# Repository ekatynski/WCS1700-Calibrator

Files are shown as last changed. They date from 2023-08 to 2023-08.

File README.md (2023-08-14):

View this project on [CADLAB.io](https://cadlab.io/project/27238). 

# WCS1700-Calibrator
A board designed to aid in calibrating six [Winson WCS1700 hall effect sensors](https://www.winson.com.tw/uploads/images/WCS1700.pdf) at the same time as well as the software needed to drive it.

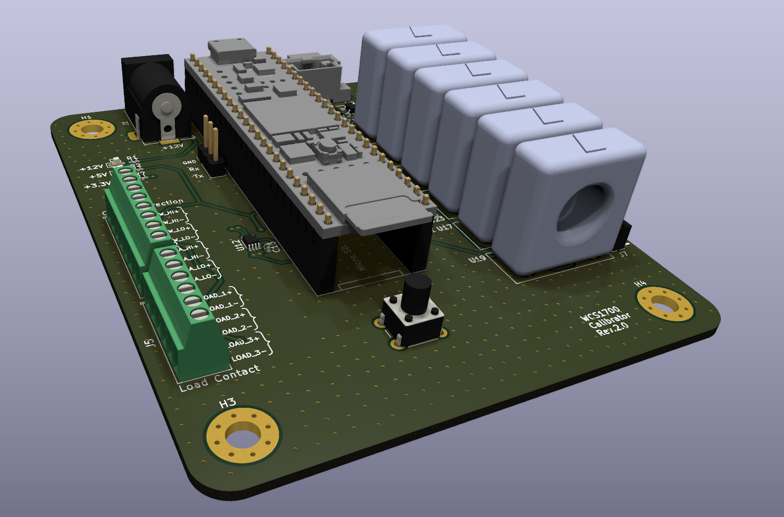
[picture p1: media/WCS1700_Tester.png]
Rendering of the completed PCB


## Requirements
1. +12V power supply rated for at least 1A with barrel jack connection (+8V will work in a pinch)
2. An adjustable current source capable of up to 60A output with a conductor small enough to fit the aperture of a WCS1700
3. A micro-USB cable with data capability
4. A Teensy 4.1 microcontroller and [completion of the necessary first use steps](https://www.pjrc.com/teensy/loader.html)
5. For best results, VSCode with the Platformio plugin installed

## Hardware
Schematic and BOM can both be found in the `/hardware/` section of this repository. Expanded description of hardware functionality coming soon.

## Software
All software can be found in the `/software/` section of this repository. Expanded description of software functionality coming soon. In addition, software updates to expand contactor control functionality and independent current volume is on the way, but the software necessary to simply monitor and report the WCS1700 hall effect sensor outputs is ready and implemented.

## Procedure
1. Slot one WCS hall effect sensor into each of the six ports on the right. This will feed them a +5V reference and allow their output voltages to be tracked via a nearby ADC
2. Inspect your Teensy 4.1. If the trace separating VIN and VUSB is cut, you should solder JP3 on the PCB. If not, you should ensure that either the aforementioned Teensy trace is intact or that the pads spanned by said trace are soldered together. **Do not do both or you risk damaging your Teensy or the board**
3. Ensure that JP1 and JP2 are not soldered simultaneously. It is okay to solder one or the other (or neither) but **do not do both or you risk damaging your board**
4. Seat your Teensy 4.1 in the pin sockets and connect it to your computer via USB
5. Route your current source conductor through the hall effect sensor apertures and attach a load
6. Apply power to the PCB
7. Monitor the serial output from the Teensy 4.1
8. Adjust your current source as desired

## Assembly Guide
An assembly guide for this board can be found in this repository at `/hardware/bom/`

## To-Do
The hardware of this project has advanced to support contactor control via relay connections. Four of these contactors form a would-be H-bridge to control load current flow direction while the remaining three allow current flow across individual load resistors to increase or decrease current volume. The hardware has also advanced to support independent current monitoring via a Tamura L01Z series hall effect sensor. The software to drive these features is not yet in place. The following is a list of development items not yet complete:

- [x] Rearrange FET position and routing to make it a superior low-side switch
- [ ] Add harness documentation
- [ ] Write code to support autocalibration of ADC `U4`
- [ ] Write code to support monitoring of Tamura L01Z Hall Effect sensor via ADC 'U5'
- [ ] Write logic to support contactor control during current monitoring after button push
- [ ] Write code to support logging recorded calibration values to an SD card
- [ ] Update instructions to allow for use of additional Tamura hall effect sensor as well as contactor control

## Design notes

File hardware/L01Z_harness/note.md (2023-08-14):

# Note:

This is retained more as a documentation example than a useful aspect. This harness usually leads to a small standalone board for better interfacing with the L01Z hall effect sensor but I haven't uploaded that, so it's not terribly useful here.

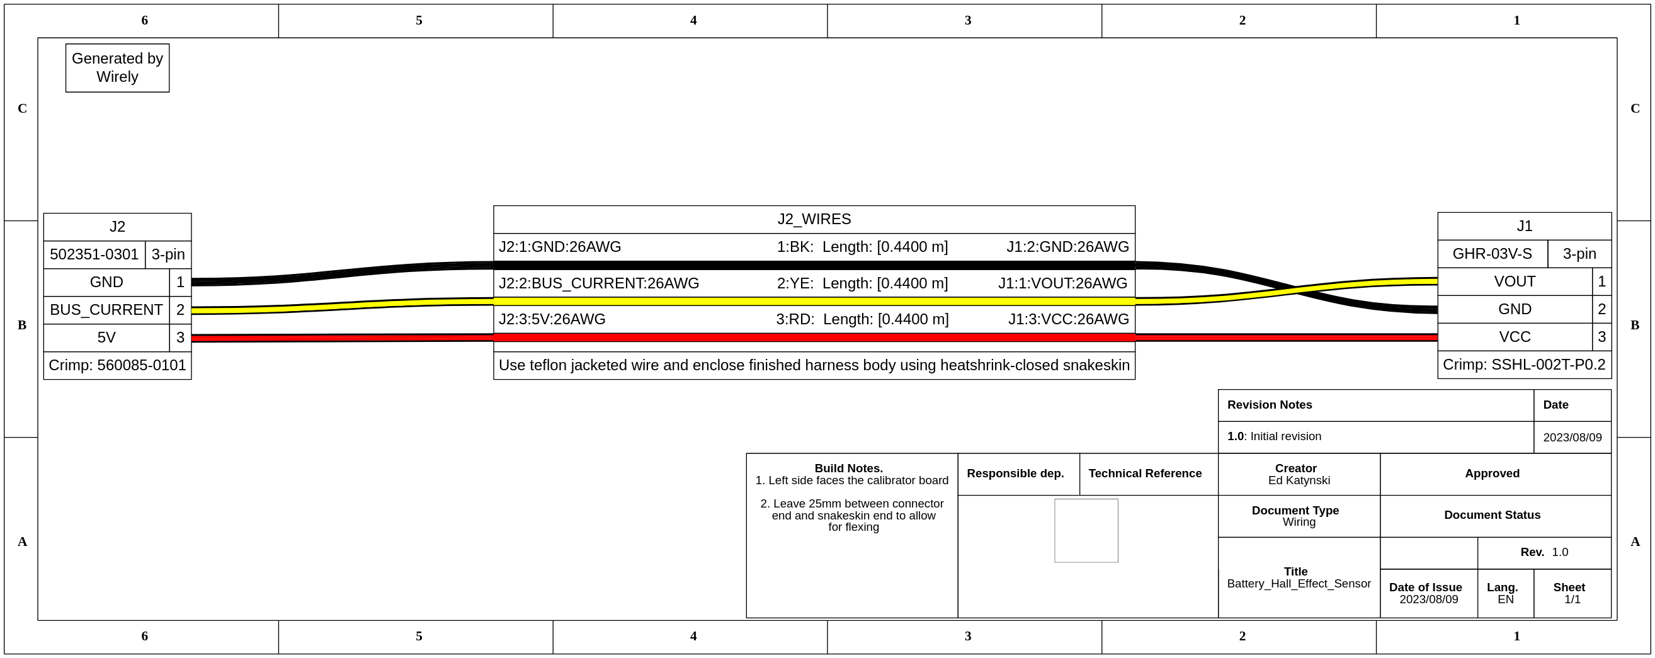
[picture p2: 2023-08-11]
hardware/L01Z_harness/Battery_Hall_Effect_Sensor.png

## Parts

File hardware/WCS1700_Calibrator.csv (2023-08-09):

Source: | /home/ed/Documents/KiCad/Work Projects/WCS1700-Calibrator/WCS1700_Calibrator.kicad_sch
Date: | Tue 08 Aug 2023 10:41:28 PM PDT
Tool: | Eeschema 7.0.6
Generator: | /app/share/kicad/plugins/bom_csv_grouped_by_value.py
Component Count: | 119
Collated Components:
Item | Qty | Reference(s) | Value | LibPart | Footprint | Datasheet | DNP | Application Note
1 | 18 | C1, C2, C10, C11, C12, C13, C15, C16, C18, C19, C21, C22, C24, C25, C27, C28, C30, C31 | 0.1uF 25V | Device:C | Capacitor_SMD:C_0402_1005Metric_Pad0.74x0.62mm_HandSolder | ~
2 | 5 | C3, C4, C5, C8, C9 | 1uF 25V | Device:C | Capacitor_SMD:C_0402_1005Metric_Pad0.74x0.62mm_HandSolder | ~
3 | 1 | C6 | 0.01uF 10V | Device:C_Small | Capacitor_SMD:C_0402_1005Metric_Pad0.74x0.62mm_HandSolder | ~
4 | 1 | C7 | 10uF 10V | Device:C | Capacitor_SMD:C_0402_1005Metric_Pad0.74x0.62mm_HandSolder | ~
5 | 6 | C14, C17, C20, C23, C26, C29 | 0.1uF 25V | Device:C_Small | Capacitor_SMD:C_0402_1005Metric_Pad0.74x0.62mm_HandSolder | ~
6 | 3 | D1, D3, D4 | 150060VS75000 | Device:LED | LED_SMD:LED_0603_1608Metric_Pad1.05x0.95mm_HandSolder | https://www.we-online.com/components/products/datasheet/150060VS75000.pdf
7 | 1 | D2 | B0520LW-7-F | Device:D_Schottky | Diode_SMD:D_SOD-123 | https://www.diodes.com/assets/Datasheets/B0520LW.pdf
8 | 4 | H1, H2, H3, H4 | MountingHole | Mechanical:MountingHole | MountingHole:MountingHole_4mm_Pad_Via | ~
9 | 1 | J1 | PJ-002B | Connector:Barrel_Jack_Switch | Connector_BarrelJack:BarrelJack_Horizontal | https://www.cuidevices.com/product/resource/pj-002b.pdf
10 | 1 | J2 | 560020-0330 | Connector_Generic_MountingPin:Conn_01x03_MountingPin | connector:CONN_560020-0330_MOL | https://tools.molex.com/pdm_docs/sd/5600200330_sd.pdf
11 | 1 | J3 | 282834-8 | Connector:Screw_Terminal_01x08 | TerminalBlock_TE-Connectivity:TerminalBlock_TE_282834-8_1x08_P2.54mm_Horizontal | https://www.te.com/usa-en/product-282834-8.datasheet.pdf
12 | 1 | J4 | Conn_01x03_Pin | Connector:Conn_01x03_Pin | Connector_PinHeader_2.54mm:PinHeader_1x03_P2.54mm_Vertical | ~
13 | 1 | J5 | 282834-6 | Connector:Screw_Terminal_01x06 | TerminalBlock_TE-Connectivity:TerminalBlock_TE_282834-6_1x06_P2.54mm_Horizontal | https://www.mouser.com/datasheet/2/418/7/ENG_CD_282834_C1-2036206.pdf
14 | 6 | J6, J7, J8, J9, J10, J11 | Conn_01x03_Socket | Connector:Conn_01x03_Socket | Connector_PinSocket_1.27mm:PinSocket_1x03_P1.27mm_Vertical | ~
15 | 3 | JP1, JP2, JP3 | Jumper_2_Open | Jumper:Jumper_2_Open | Jumper:SolderJumper-2_P1.3mm_Open_TrianglePad1.0x1.5mm | ~
16 | 5 | Q1, Q2, Q3, Q4, Q5 | AO3422 | Transistor_FET:AO3400A | Package_TO_SOT_SMD:SOT-23 | http://www.aosmd.com/pdfs/datasheet/AO3400A.pdf
17 | 13 | R1, R2, R7, R8, R9, R14, R15, R16, R17, R18, R19, R20, R21 | 4.7K | Device:R_US | Resistor_SMD:R_0402_1005Metric_Pad0.72x0.64mm_HandSolder | ~
18 | 4 | R3, R4, R5, R6 | 2.2K 0.1% | Device:R_US | Resistor_SMD:R_0402_1005Metric_Pad0.72x0.64mm_HandSolder | ~
19 | 7 | R10, R11, R12, R13, R22, R23, R24 | 500R | Device:R_US | Resistor_SMD:R_0402_1005Metric_Pad0.72x0.64mm_HandSolder | ~
20 | 1 | R25 | 10K | Device:R_US | Resistor_SMD:R_0402_1005Metric_Pad0.72x0.64mm_HandSolder | ~ | DNP
21 | 1 | SW1 | ‎1825910-6‎ | Switch:SW_Push | Button_Switch_THT:SW_PUSH_6mm_H8mm | https://media.digikey.com/pdf/Data%20Sheets/Panasonic%20Electronic%20Components/ESE-20C,D.pdf
22 | 1 | TH1 | 0ZCJ0050AF2E | Device:Thermistor_PTC_US | Fuse:Fuse_1206_3216Metric_Pad1.42x1.75mm_HandSolder | https://www.belfuse.com/resources/datasheets/circuitprotection/ds-cp-0zcj-series.pdf
23 | 6 | TP1, TP2, TP3, TP4, TP5, TP6 | TestPoint | Connector:TestPoint | TestPoint:TestPoint_Pad_D1.0mm | ~
24 | 2 | U1, U2 | MAX6107 | Reference_Voltage:MAX6107 | Package_TO_SOT_SMD:SOT-23 | http://datasheets.maximintegrated.com/en/ds/MAX6100-MAX6107.pdf
25 | 1 | U3 | LT1962EMS8-5#TRPBF | Regulator_Linear:LT1962-5 | Package_SO:MSOP-8_3x3mm_P0.65mm | https://www.analog.com/media/en/technical-documentation/data-sheets/1962fb.pdf
26 | 2 | U4, U5 | MCP3208 | :MCP3208_1 | Package_SO:SOIC-16_3.9x9.9mm_P1.27mm | http://ww1.microchip.com/downloads/en/DeviceDoc/21298c.pdf
27 | 1 | U6 | TXB0106PW | level_shift:TXB0106PW | Package_SO:TSSOP-16_4.4x5mm_P0.65mm | https://www.ti.com/lit/ds/symlink/txb0106.pdf
28 | 7 | U7, U8, U9, U10, U14, U15, U16 | TLP241A(TP1,F | Relay_SolidState:TLP222A | OptoDevice:OnSemi_CASE100CY | https://toshiba.semicon-storage.com/info/TLP241A_datasheet_en_20200217.pdf?did=14237&prodName=TLP241A
29 | 1 | U11 | SN74AUC2G08DCUR | 74xGxx:74AUC2G08 | Package_SO:VSSOP-8_2.3x2mm_P0.5mm | https://www.ti.com/lit/ds/symlink/sn74auc2g08.pdf
30 | 1 | U12 | 74LVC2G240DC,125 | 74xGxx:74LVC2G240 | Package_SO:VSSOP-8_2.3x2mm_P0.5mm | http://www.ti.com/lit/sg/scyt129e/scyt129e.pdf
31 | 1 | U13 | Teensy4.1 | teensy:Teensy4.1 | teensy:Teensy41
32 | 6 | U17, U19, U21, U23, U25, U27 | WCS1700 | Sensor_Hall_Effect:WCS1700 | Sensor_Hall_Effect:WCS1700 | http://www.winson.com.tw/uploads/images/WCS1700.pdf |  | http://www.winson.com.tw/uploads/images/WCS%20Application%20note.pdf
33 | 6 | U18, U20, U22, U24, U26, U28 | ADR02AUJZ | v_ref:ADR02AUJZ | Package_TO_SOT_SMD:SOT-23-5_HandSoldering | https://www.analog.com/media/en/technical-documentation/data-sheets/ADR01_02_03_06.pdf

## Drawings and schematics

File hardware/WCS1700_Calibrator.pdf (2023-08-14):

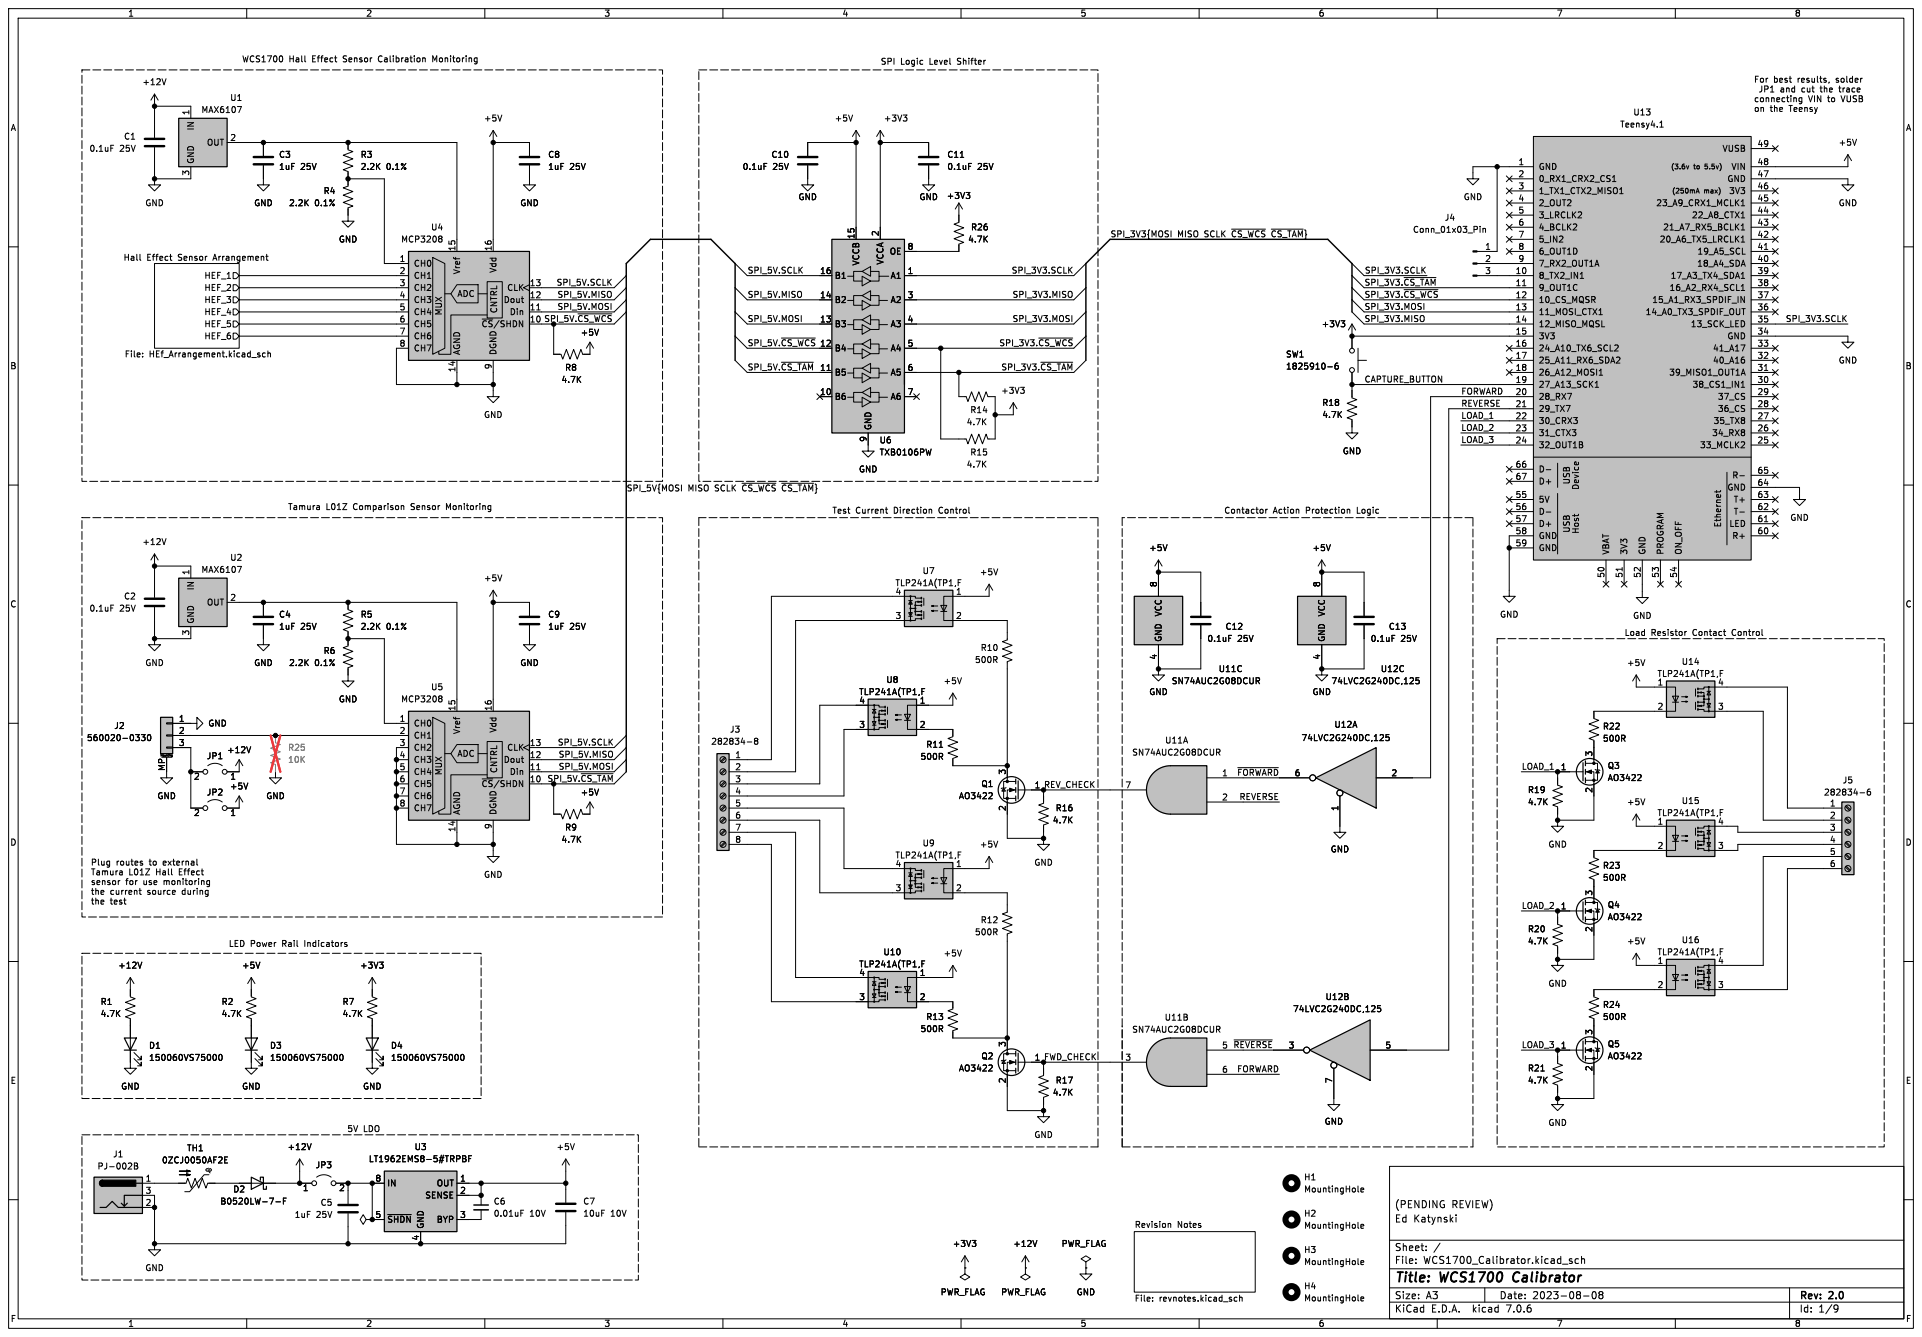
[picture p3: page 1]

Load Resistor Contact Control U11C

the current source during
the test

LED Power Rail Indicators

5V LDO
LT1962EMS8-5#TRPBF OUT 1 SENSE 2 BYP 3 GND

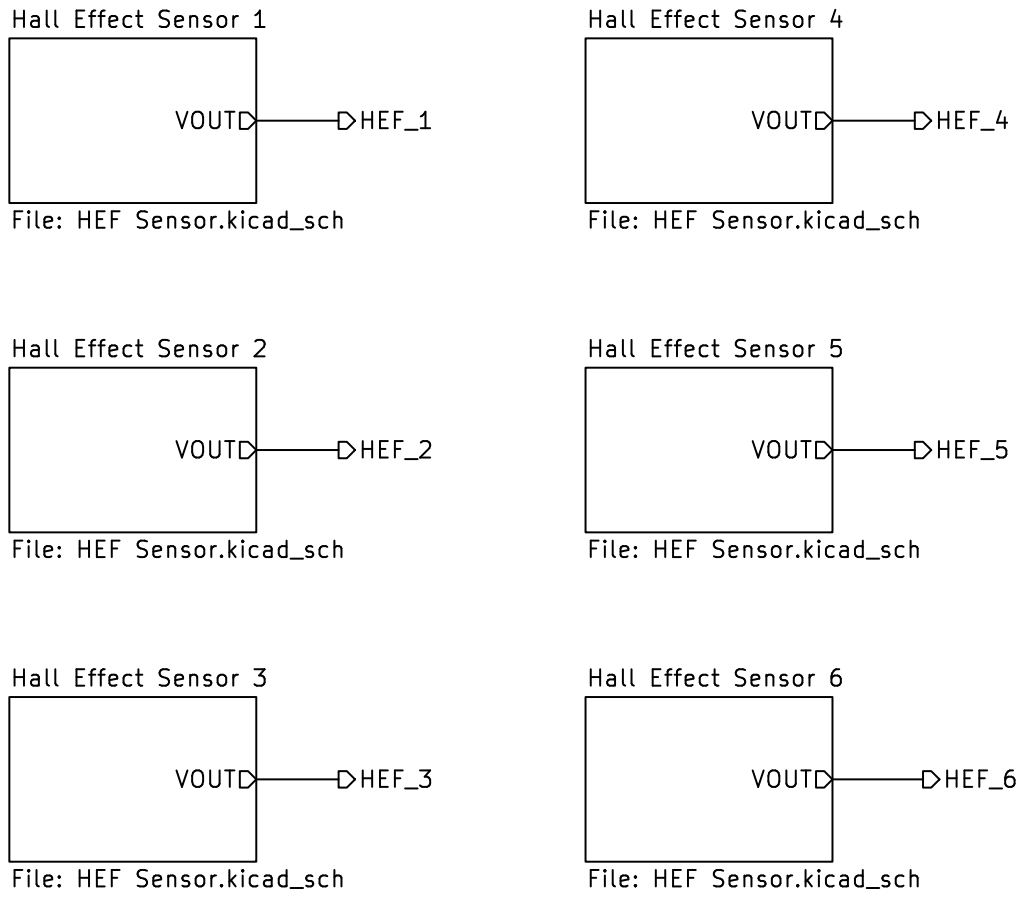
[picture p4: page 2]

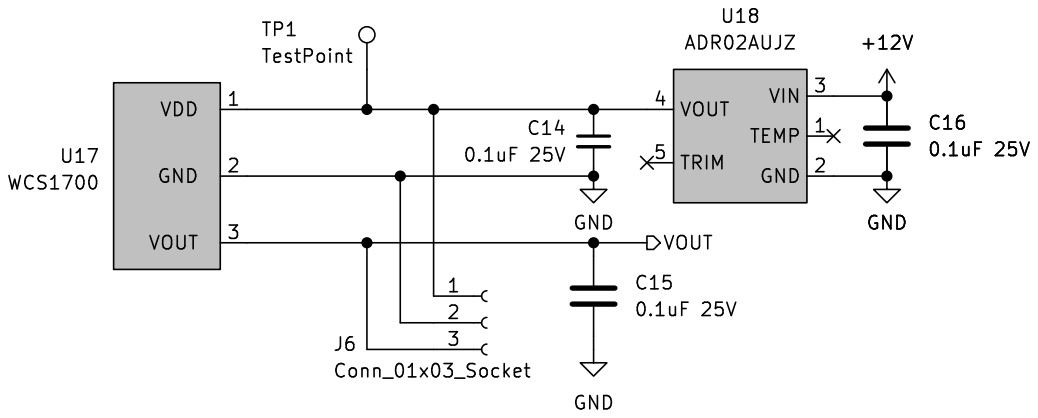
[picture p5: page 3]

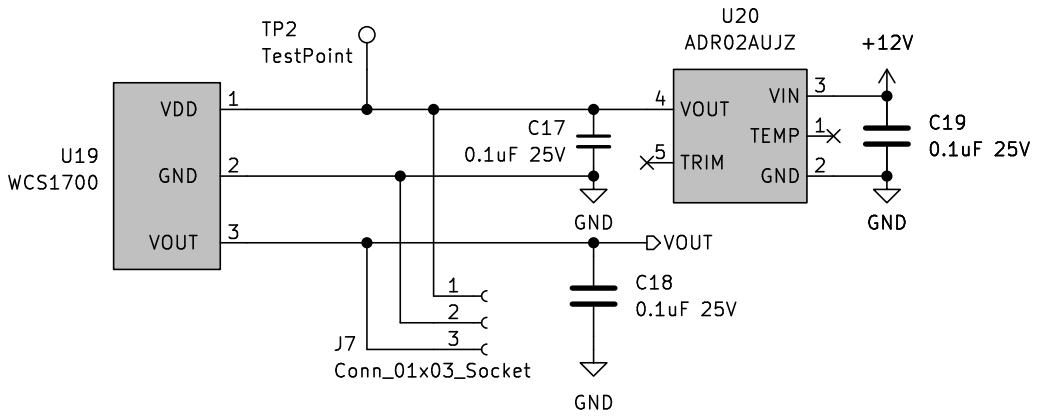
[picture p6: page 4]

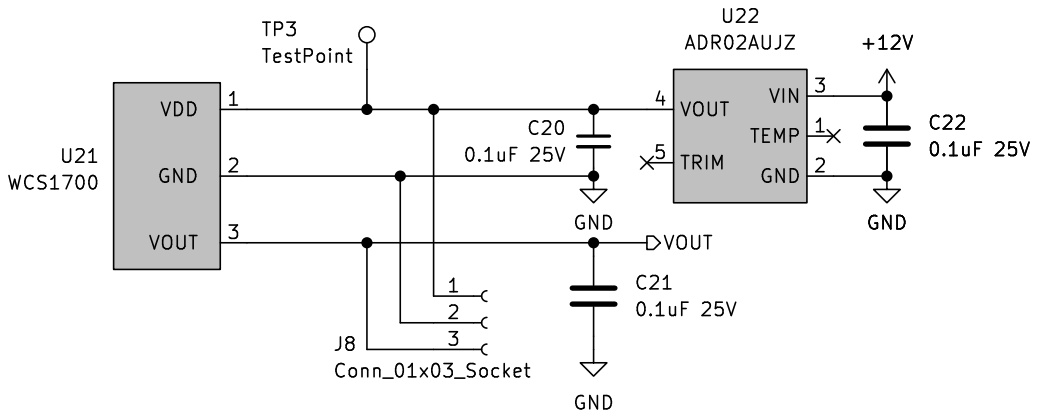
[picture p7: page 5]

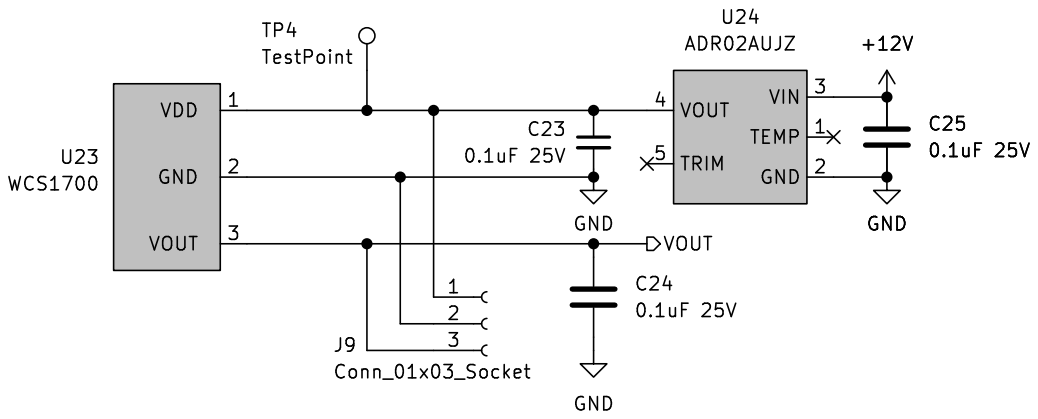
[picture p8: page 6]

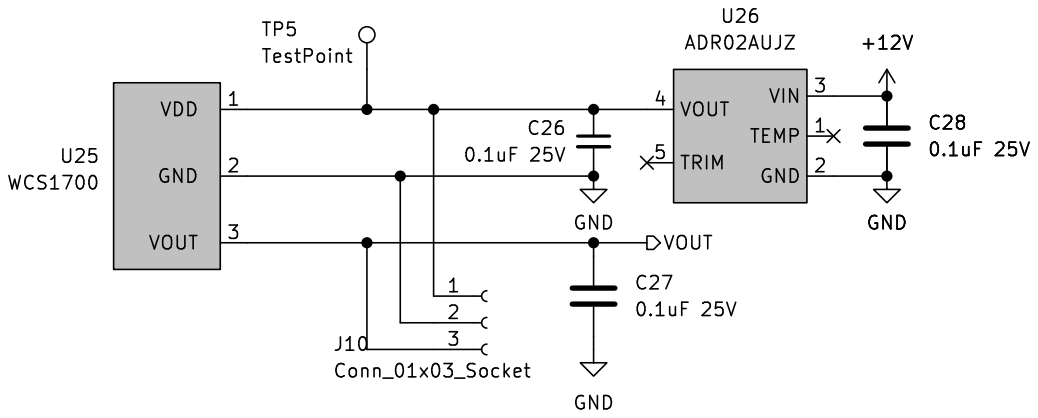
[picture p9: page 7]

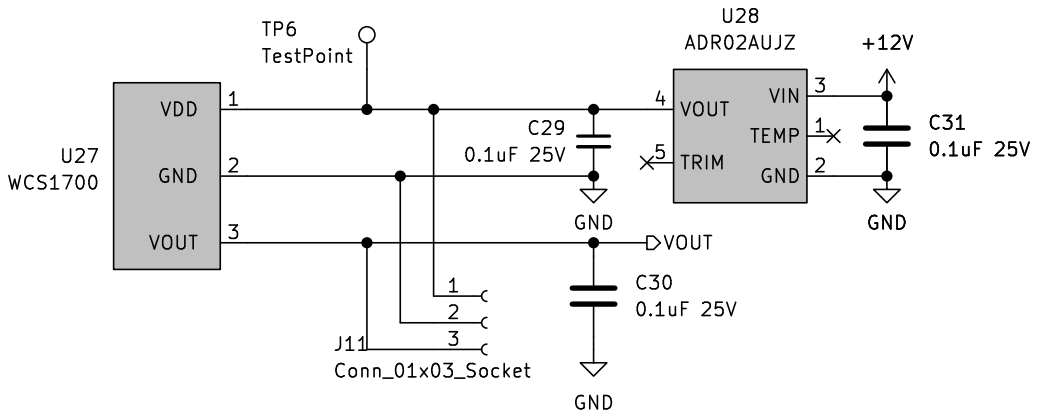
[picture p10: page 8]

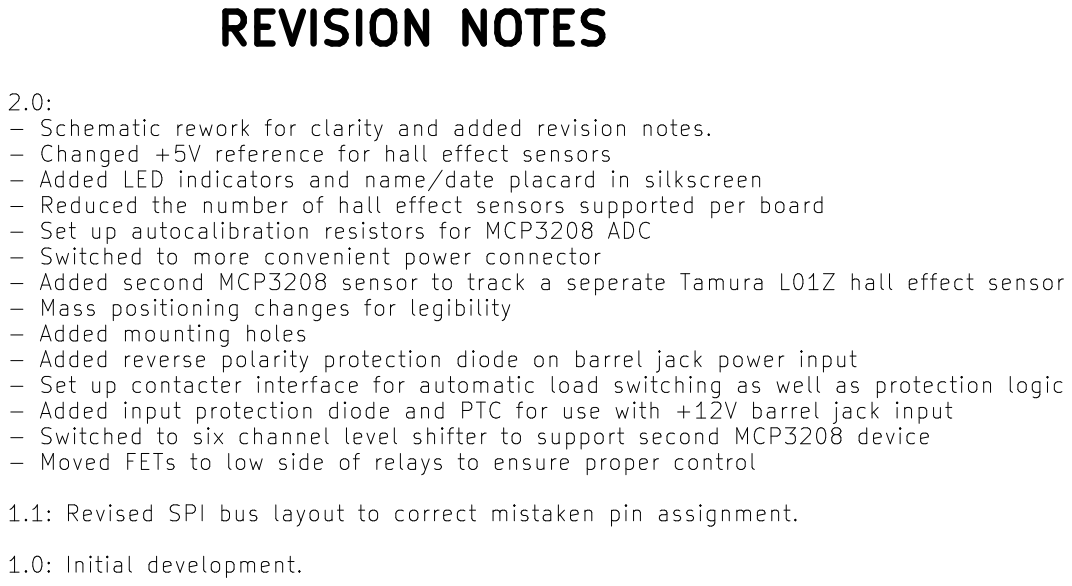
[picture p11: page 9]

- Moved FETs to low side of relays to ensure proper control

1.1: Revised SPI bus layout to correct mistaken pin assignment.

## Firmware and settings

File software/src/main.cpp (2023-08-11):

#include <Arduino.h>
#include <SPI.h>
#include <vector>
#include "Mcp320x.h"

const int WCS_CS = 10;        // WCS1700 ADC CS pin
const int TAMURA_CS = 11;     // Tamura hall effect sensor CS pin
const int ADC_VREF = 4500;    // 4.5V Vref
const int ADC_CLK = 500000;   // SPI clock 500kHz
const int SPLS = 10;          // 10 samples

float gain = 1.00;            // ADC gain, set by hand for now
int offset = 0;               // ADC offset (bits), initially set to zero

uint16_t data[SPLS] = {0};    // array to store samples from each adc.read() call
int avg[8] = {0};

// indexing channel enums to integers to ease looping
MCP3208::Channel channels[8] = {
  MCP3208::Channel::SINGLE_0,
  MCP3208::Channel::SINGLE_1,
  MCP3208::Channel::SINGLE_2,
  MCP3208::Channel::SINGLE_3,
  MCP3208::Channel::SINGLE_4,
  MCP3208::Channel::SINGLE_5,
  MCP3208::Channel::SINGLE_6,
  MCP3208::Channel::SINGLE_7
};

MCP3208 adc(ADC_VREF, WCS_CS);

void setup() {
  // configure PIN mode
  pinMode(WCS_CS, OUTPUT);
  pinMode(TAMURA_CS, OUTPUT);

  // set initial PIN state
  digitalWrite(WCS_CS, HIGH);
  digitalWrite(TAMURA_CS, HIGH);

  // initialize serial
  Serial.begin(115200);
  Serial.println("Starting up...");

  // initialize SPI interface for MCP3208
  SPISettings settings(ADC_CLK, MSBFIRST, SPI_MODE3);
  SPI.begin();
  SPI.beginTransaction(settings);

   // report gain and offset
  Serial.println("Gain: " + String(gain) + "\tOffset: " + String(adc.toAnalog(offset)) + " mV");

  // prepare to report
  Serial.println("\t");
  delay(1000);
}

void loop() {
  // timestamping
  Serial.println("Sample time: " + String((float(millis()) / 1000.0f)) + "s");
  
  // cycle through each channel, taking samples on each
  for (int i = 0; i < 8; i++) {
    // start sampling
    adc.read(channels[i], data);
    
    // average the samples collected for each channel
    for (int j = 0; j < SPLS; j++) {
      avg[i] += data[j];
    }
    avg[i] /= SPLS;
  
    // correct for gain and scale error
    avg[i] = uint16_t(float(avg[i] - offset) / gain);
  }

  // print out the averages for each channel
  for (int i = 0; i < 8; i++) {
    Serial.println("Channel " + String(i) + ":\t" + String(adc.toAnalog(avg[i])) + " mV\t(" + String(avg[i]) + ")");
  }

  Serial.println();
  delay(100);
}

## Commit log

2023-08-09 Mass import of project files
    [ADC_and_level_shift.kicad_sch, HEF Sensor.kicad_sch, HEf_Arrangement.kicad_sch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]
2023-08-09 Redid BOM, schematic, and assembly guide
    [WCS1700_Calibrator.csv]
2023-08-09 Moved all files into hardware subdirectory
    [ADC_and_level_shift.kicad_sch, HEF Sensor.kicad_sch, HEf_Arrangement.kicad_sch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]
2023-08-09 Added Teensy software to drive the project
2023-08-09 Debadged the board.
    [WCS1700_Calibrator.kicad_pcb]
2023-08-09 Added WCS1700 and Teensy library files
    [WCS1700_Calibrator.kicad_pcb]
2023-08-11 Edited schematic to relocated FETs as proper low-side switches
    [WCS1700_Calibrator.kicad_sch, revnotes.kicad_sch]
2023-08-11 Replotted due to forgotten +5V flag in schematic
    [WCS1700_Calibrator.kicad_sch]
2023-08-11 Replotted for easier reference designation
    [WCS1700_Calibrator.kicad_sch]
2023-08-11 Rerouted FETs to match schematic revisions
    [WCS1700_Calibrator.kicad_pcb, WCS1700_Calibrator.kicad_sch]
2023-08-11 Added teardrops and droped old assembly guide
    [WCS1700_Calibrator.kicad_pcb]
2023-08-11 Added via stitching
    [WCS1700_Calibrator.kicad_pcb]
2023-08-11 Assembly guide update
2023-08-11 A little additional manual via stitching
    [WCS1700_Calibrator.kicad_pcb]
2023-08-11 3D model update
    [WCS1700_Calibrator.kicad_pcb]
2023-08-11 Manual rescue of .kicad_pcb file due to git merge error
    [WCS1700_Calibrator.kicad_pcb]
2023-08-11 Added Tamura hall effect sensor ADC chip select pin
2023-08-11 Set Tamura CS pin high permanently for now
2023-08-11 Lowered Vref voltage
2023-08-11 Added note for use of hall effect sensor harness
2023-08-11 Added Wirely harness file and diagram
2023-08-14 Added output enable 3.3V pull-up resistor on U6
    [WCS1700_Calibrator.kicad_sch]
2023-08-14 Placed new pull-up resistor and redid assembly guide
    [WCS1700_Calibrator.kicad_pcb]
2023-08-14 Replaced misplaced resistors and redid assembly guide
    [WCS1700_Calibrator.kicad_pcb]
2023-08-14 Update note.md
    Updated disclaimer regarding harness diagram for L01Z board.
2023-08-14 Added photo of the device for display in the README
2023-08-14 Update README.md
    Added photo of the calibrator device to the README
2025-05-18 Fixed massive GitHub confusion.
    [HEF Sensor.kicad_sch, HEf_Arrangement.kicad_sch, WCS1700_Calibrator.kicad_pcb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]
2025-10-27 Updated 3D models.
    [WCS1700_Calibrator.kicad_pcb]
